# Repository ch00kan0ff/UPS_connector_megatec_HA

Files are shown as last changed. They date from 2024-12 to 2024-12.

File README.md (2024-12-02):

# Монитор ИБП с протоколом Megatec для HomeAssistant
Устройство на базе контроллера ESP8266 для получения данных по RS232 от источника бесперебойного питания (ИБП) и передачи их в HomeAssistant.

## Схема
Схема сборки на рисунке ниже. Исходник схемы, если надо /files/UPS_Control.fzz

**Важно!** Если не заработало после сборки, то можно попробовать менять местами RX-TX. Их тут две пары: от контроллера к преобразователю и от преобразователя к плате ИБП. То, как указано на схеме работает в моем случае.
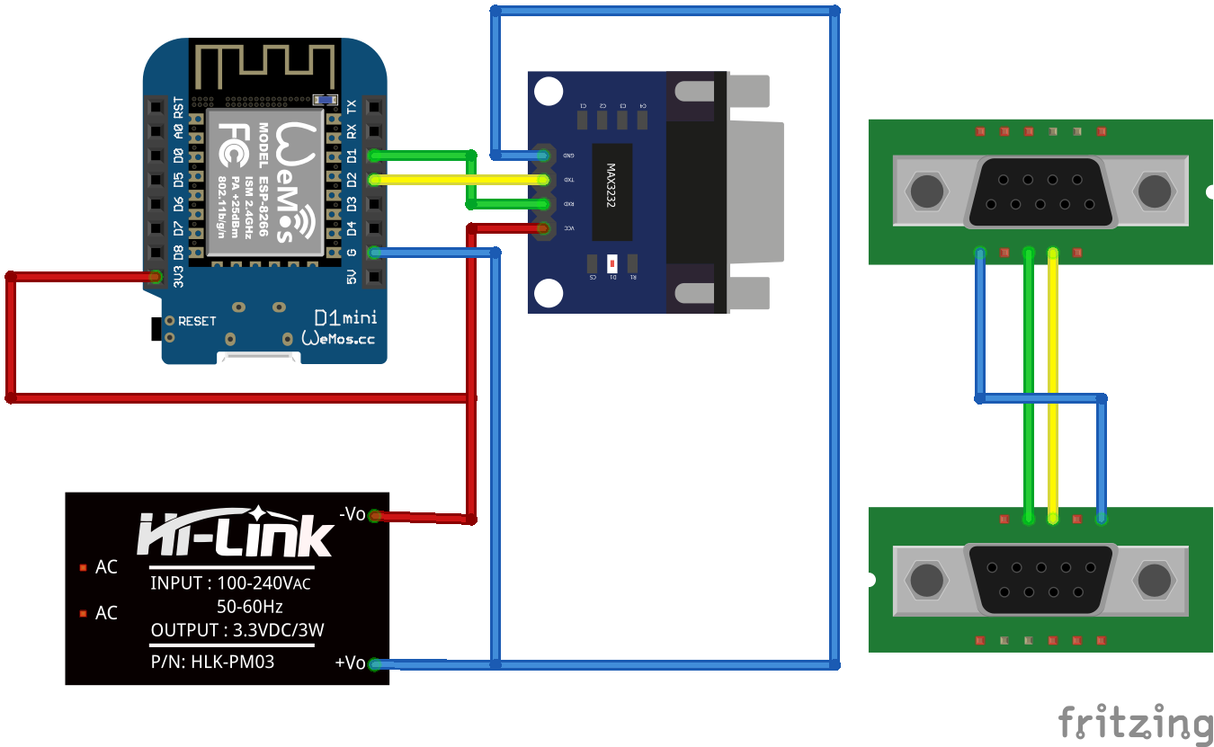
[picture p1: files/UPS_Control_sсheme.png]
Схема сборки устройства


Вместо Wenmos вполне можно использовать другие контроллеры, но тестировалось только на нём. В качестве преобразователя нужен MAX3232, так как он работает от 3.3V. MAX232 судя по всему только от 5 вольт.

## Прошивка
Разрабатывал и прошивал в ArduinoIDE. Файл прошивки /src/UPS_Connector.ino. Для сборки прошики нужны некоторые библиотеки, ссылки на них указаны в комментариях в самом коде прошивки. Все устанавливаются через менеджер библиотек ArduinoIDE. Для работы ESPSoftwareSerial нужна последняя версия платы, поэтому перед сборкой лучше обновить платы.

Настройки прошивки можно не трогать, если паять по схеме. Либо поменять пины для ESPSoftwareSerial, если используете другие пины. 

Перед прошивкой желательно затереть Flash память, так как используется сохранение настроек в память и при наличии там мусора могут быть проблемы. На новых модулях этого можно не делать, должно работать и так.

Для wemos выложен также готовый бинарник, можно прошить его, если ничего не планируете менять в самой прошивке. Файл в /bin/UPS_connector.ino.d1_mini.bin

## Возможности
### Сбор данных с ИБП
Реализован опрос ИБП по протоколу Megatec, сделано получение следующих данных:
- InputVoltage. Входное напряжение
- FailVoltage. Напряжение ошибки
- OutputVoltage. Выходное напряжение
- Output load. Загрузка ИБП по току в процентах от максимальной загрузки.
- InputFrequency. Частота тока. По протоколу написано, что это для входной линии, судя по тестам - для выходной. Однако, оставлено так, потому что не смог понять, это особенность моего тестового ИБП или всё-таки стандарт.
- BatteryVoltage. Напряжение батареи. Для On-line ИБП выдает напряжение на одной банке. Для корректного отображения в HA на портале есть множители. Смотри ниже в описании портала.
- Tempetature. Температура ИБП.
- UtilityFail. Флаг ошибки, когда возникают проблемы с вводной сетью.
- LowBattery. Флаг ошибки при низком заряде батареи.
- Bypass. Сигнал включенного байпаса.
- GeneralFail. Что-то типа общей ошибки в работе ИБП.
- OnLine. Тип ИБП. Если включено, значит On-line.
- TestInProgress. Флаг запущенного теста батарей.
- ShutDownActive. Флаг того, что запущен процесс выключения ИБП.
- Beeper. Состояние звукового сигнала.

И отдельно сделан параметр потери связи с ИБП ConnectionFail. Возводится если контроллер не может долго получить данные от ИБП. В таком случае он будет пытаться восстановить связь раз в 5 минут автоматически.

### Передача данных в HA
Подключение через службу MQTT с AutoDyscovery. Чтобы устранить возможные конфликты - сделана автоматическая генерация GUID при первом старта устройства или при затирании flash.
Само устройство после добавления выглядит так:

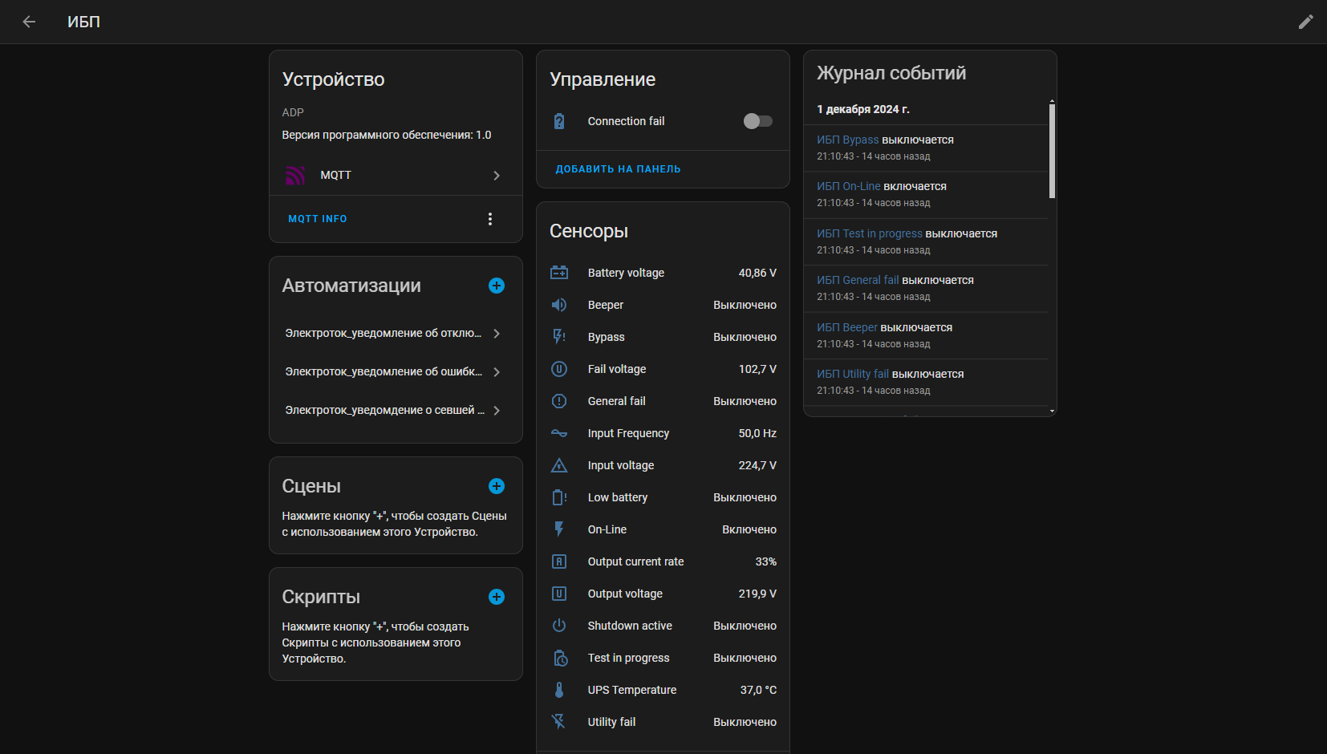
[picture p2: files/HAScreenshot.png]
HAScreenshot


Сделана дополнительная карточка для большей наглядности. При создании карточки использовались стандартная карточка picture-elements, [custom:button-card](https://github.com/custom-cards/button-card) и [cardmod](https://github.com/thomasloven/lovelace-card-mod).
Вид карточки показан на скриншоте снизу. Исходник картинки подложки (GIMP) лежит тут: files/HAUPSCardBackground.xcf. Сама картинка подложка тут: HA_Card/HAUPSCardBackground.xcf. YAML карточки тут: HA_Card/HA_card.yaml. В карточке надо будет указать корректные наименования объектов, так как они будут сохранены в HA.

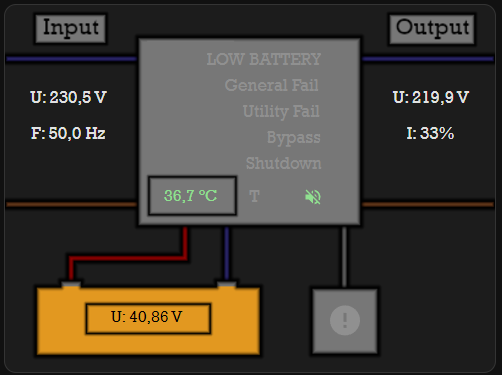
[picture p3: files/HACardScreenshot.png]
HACardScreenshot


ConnectionFail в HA сделан выключателем. И его можно выключить, тогда контроллер попытается восстановить связь с ИБП. При включении этого выключателя, связь с ИБП не будет прерываться и состояние выключателя вернется в выключенное состояние.

При потере питания, отвала сети и т.д. устройство в HA помечается недоступным спустя минуту (примерно).

### Портал на устройстве и настройки
Реализован портал, для настройки подключения и получения данных с устройства без HA. После первого включения устройства, создается точка доступа UPSControl с паролем 1234567890 (можно поменять в настройках). После подключения к ней надо перейти по адресу 192.168.1.1. Откроется окно портала. Там нужно ввести реквизиты доступа к Wi-Fi и подключения к MQTT серверу, к которому подключен HA. Топик для дискавери по умолчанию установлен стандартный homeassistant, если необходимо, то можно его поменять. После нажатия Save and Connect контроллер пытается подключиться к сети и MQTT серверу. Если коннект успешен, то контроллер начинает отправлять данные в HA. На портал в таком случае можно зайти, перейдя в браузере по IP, который выделил для контроллера роутер.

Сделано автоматическое восстановление связи с Wi-Fi и MQTT. Если коннект пропал, то контроллер поднимает точку доступа UPSControl, как при первом старте. И пытается раз 3 минуты подключиться заново.

Помимо настроек сети на портале доступно:
- Просмотр всех параметров, полученных от ИБП. Обновляются онлайн.
- Выключение ConnectionFail по аналогии с таким выключателем в HA (смотри выше).
- Настройка батарей. Можно указать сколько ячеек в одной батарее и сколько последовательно соединено батарей в сборке. На основе этой информации контроллер считает вольтаж всей баратеи и именно эту цифру передает в HA и на портал.
- OTA обновления прошивки по воздуху. Доступно через отдельную страницу 192.168.1.1/ota_update, либо надо указать IP адрес от роутера вместо "192.168.1.1".

Скриншоты портала ниже:

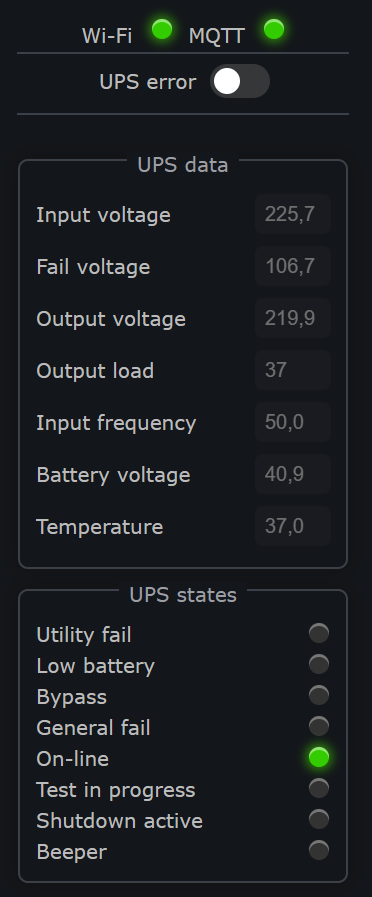
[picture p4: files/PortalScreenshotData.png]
PortalScreenshotData


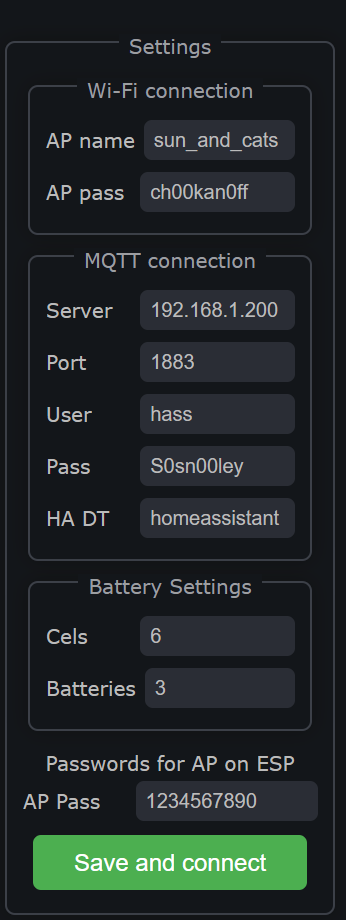
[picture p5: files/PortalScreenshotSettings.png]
PortalScreenshotSettings


## Поддерживаемые ИБП
По идее должны поддерживаться любые ИБП с протоколом Megatec и выходом RS232. Однако тестировалось только на [Штиль SW1000L](https://www.shtyl.ru/catalog/ibp/odnofaznye/nastennye/sw1000l-1000-va-900-vt/) с картой расширения [IC-RS232/Dry contacts](https://www.shtyl.ru/catalog/ibp/aksessuary/karty-monitoringa/ic-rs-232-dry-contacts/)

## TODO
В будущем планируется сделать отправку дополнительных команд на ИБП:
- Включение/отключение звука
- Запуск/остановка тестов

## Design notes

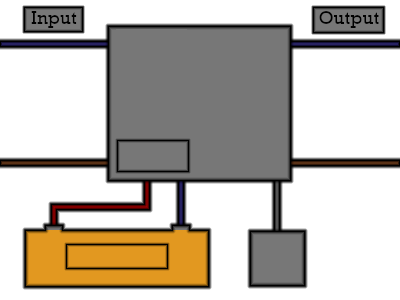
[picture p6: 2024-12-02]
HA_card/HAUPSCardBackground.png

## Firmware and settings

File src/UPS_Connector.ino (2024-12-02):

/*-----Подключение необходимых библиотек-----*/
#include <ESP8266WiFi.h>                //для работы с сетью
#include <GyverPortal.h>                //для работы страницы настроек, доступной из локальной сети или при подключении к самому устройству. https://github.com/GyverLibs/GyverPortal/tree/main
#include <EEPROM.h>                     //для работы с памятью
#include <ArduinoHA.h>                  //Библиотека для отправки данных в HA. https://github.com/dawidchyrzynski/arduino-home-assistant
#include <SoftwareSerial.h>             //Библиотека для обмена через софт сериал. Через аппаратный оно не особо хотело работать. https://github.com/plerup/espsoftwareserial
extern "C" {
#include "user_interface.h"             //для переименования устройства в списке роутера
}

/*-----Объявление необходимых переменных-----*/
GyverPortal portal;                     //переменная портала
WiFiClient espClient;                   //переменная wi-fi клиента, через которого в дальнейшем подключаемся к сети

//Переменные для обмена с HA
HADevice device;
HAMqtt mqtt(espClient, device, 20);     //20 - количество сенсоров. Взято с запасом, на всякий случай. Думаю, что можно уменьшить до реального количества сенсоров
HASensorNumber sIPV("InputVoltage", HASensorNumber::PrecisionP1);
HASensorNumber sFV("FailVoltage", HASensorNumber::PrecisionP1);
HASensorNumber sOPV("OutputVoltage", HASensorNumber::PrecisionP1);
HASensorNumber sOPC("Output load");
HASensorNumber sIPF("InputFrequency", HASensorNumber::PrecisionP1);
HASensorNumber sBATV("BatteryVoltage", HASensorNumber::PrecisionP2);
HASensorNumber sTEMP("Tempetature", HASensorNumber::PrecisionP1);
HABinarySensor sUF("UtilityFail");//b7
HABinarySensor sLB("LowBattery");//b6
HABinarySensor sBA("Bypass");//b5
HABinarySensor sGF("GeneralFail");//b4
HABinarySensor sOL("OnLine");//b3
HABinarySensor sTP("TestInProgress");//b2
HABinarySensor sSD("ShutDownActive");//b1
HABinarySensor sBP("Beeper");//b0
HASwitch sCF("ConnectionFail");


static DNSServer _SP_dnsServer;         //переменная для DNS сервера

#define SP_AP_IP 192,168,1,1            //IP адрес портала для работы в режиме поднятой точки доступа на ESP
IPAddress apIP(SP_AP_IP);               //переменная для адреса, определенного в строке выше
IPAddress subnet(255, 255, 255, 0);     //подсеть
IPAddress nullAddr(0,0,0,0);            //пустой адрес, для сброса настроек

EspSoftwareSerial::UART mySerial;       //Объявляем порт

String WIFI_AP_NAME;                    //наименование точки доступа для подключения к wi-fi
String WIFI_PASSWORD;                   //пароль для подключения к точке доступа
String MQTT_ADR;                        //адрес mqtt сервера
String MQTT_PORT;                       //порт mqtt сервера
String MQTT_USER;                       //имя пользователя для подключения к mqtt
String MQTT_PAS;                        //пароль для  подключения к mqtt
String WIFI_SOFTAP_PAS;                 //пароль для точки доступа, которая поднимается на ESP. Если не задан, то по умолчанию 1234567890
int status = WL_IDLE_STATUS;            //статус соединения Wi-Fi
unsigned long lastReconnectAttempt = 0; //время последней попытки подключения к mqtt


bool WiFiStatus;                        //Статус Wi-fi подключения к роутеру: 1-ОК, 0 не ОК
bool mode = 0;                          //Переменная режима работы сети: 1 - точка доступа на ESP, 0 - работа в локальной сети

bool isConnectionCrash = 0;             //флаг того, что соединение с Wi-Fi
unsigned long lastCrashReconnect = 0;   //переменная для хранения времени последней попытки подключения при аварии
unsigned long UPSConnectCrash = 0;      //переменная для хранения времени отвала связи с ИБП для попытки восстановления

byte firstStart;                        //Переменная для первого запуска. 137 - НЕ первый старт, всё остальное - первый старт

// Переменные для получения данных от ИБП. Стандарт написан тут: https://networkupstools.org/protocols/megatec.html
float ipv;        //Входное напряжение
float fv;         //Напряжение ошибки
float opv;        //Выходное напряжение
int opc;          //Ток потребителей
float ipf;        //Входная частота тока
float batv;       //Напряжение батареи
float temp;       //Температура
int b7;           //Ошибка сети
int b6;           //Батарея разряжена
int b5;           //Байпас включен
int b4;           //Общая ошибка ИБП
int b3;           //ИБП в режиме ожидания, 0 в работе
int b2;           //Идет тест
int b1;           //Включено завершение работы
int b0;           //Сигнал включен

//Дополнительные переменные
int cDelay = 100;               //Период отправки сообщений. То что тут указано позже в коде меняется на 10000. Учитывая, что команды отправляются по очереди F и Q1, то реальный интервал получения данных будет раз в 20 секунд.
int cTimer = 0;                 //Переменная таймер для отправки сообщений
int rDelay = 9000;              //Период ожидания ответа от ИБП после отправки команды
int rTimer = 0;                 //Переменная таймер для ожидания ответа
int notGetDataCounter = 0;      //Счётчик неполученных ответов
bool isDataGetted = true;       //Флаг успешного приема данных
bool isUPSUnavailable = false;  //Флаг недоступности ИБП
String devGuid;                 //идентификатор устройства
String HADiscoveryTopic;        //Топик для автоопределения в HA 
bool isSendF = false;           //Маркер отправки команды F
int cellCount = 0;              //Количество ячеек в батарее, для 12 вольтовой батареи это 6
int batCount = 0;               //Количество батарей, подключенных последовательно!

/*-----Функция разбора строки, полученной от ИБП-----*/
void parseUPSResponse(String str){
  str = str.substring(1);  //первым символом там скобка, отрезаем его
  ipv = (str.substring(0,5)).toFloat();
  fv = (str.substring(6,11)).toFloat();
  opv = (str.substring(12,17)).toFloat();
  opc = (str.substring(18,21)).toInt();
  ipf = (str.substring(22,26)).toFloat();
  batv = (str.substring(27,31)).toFloat();
  batv = batv * cellCount * batCount;
  temp = (str.substring(32,36)).toFloat();
  b7 = (str.substring(37,38)).toInt();
  b6 = (str.substring(38,39)).toInt();
  b5 = (str.substring(39,40)).toInt();
  b4 = (str.substring(40,41)).toInt();
  b3 = (str.substring(41,42)).toInt();
  b2 = (str.substring(42,43)).toInt();
  b1 = (str.substring(43,44)).toInt();
  b0 = (str.substring(44,45)).toInt();
}

/*------Конструктор страницы портала-----*/
void build(){
  GP.BUILD_BEGIN();
  GP.THEME(GP_DARK);
  GP.PAGE_TITLE("UPS Control");
  GP.UPDATE("wfst,mqst,sw,pIPV,pFV,pOPV,pOPC,pIFP,pBATV,pTEMP,pUF,pLB,pBA,pGF,pOL,pTP,pSD,pBP",cDelay);

  GP.LABEL("Wi-Fi ");
  GP.LED_GREEN("wfst",WiFiStatus);            
  GP.LABEL(" MQTT ");
  GP.LED_GREEN("mqst",mqtt.isConnected());
  GP.BREAK();
  GP.HR();

  GP.LABEL("UPS error ");
  GP.SWITCH("sw", isUPSUnavailable);
  GP.BREAK();
  GP.HR();
  GP.BREAK();

  GP.BLOCK_BEGIN(GP_THIN,"100%","UPS data");
  GP.BOX_BEGIN();
  GP.LABEL("Input voltage");
  GP.NUMBER_F("pIPV", "", ipv, 1, "25%", true);
  GP.BOX_END();
  GP.BOX_BEGIN();
  GP.LABEL("Fail voltage");
  GP.NUMBER_F("pFV", "", fv, 1, "25%", true);
  GP.BOX_END();
  GP.BOX_BEGIN();
  GP.LABEL("Output voltage");
  GP.NUMBER_F("pOPV", "", opv, 1, "25%", true);
  GP.BOX_END();
  GP.BOX_BEGIN();
  GP.LABEL("Output load");
  GP.NUMBER("pOPC", "", opc, "25%", true);
  GP.BOX_END();
  GP.BOX_BEGIN();
  GP.LABEL("Input frequency");
  GP.NUMBER_F("pIFP", "", ipf, 1, "25%", true);
  GP.BOX_END();
  GP.BOX_BEGIN();
  GP.LABEL("Battery voltage");
  GP.NUMBER_F("pBATV", "", batv, 2, "25%", true);
  GP.BOX_END();
  GP.BOX_BEGIN();
  GP.LABEL("Temperature");
  GP.NUMBER_F("pTEMP", "", temp, 1, "25%", true);
  GP.BOX_END();
  GP.BLOCK_END();

  GP.BLOCK_BEGIN(GP_THIN,"100%","UPS states");
  GP.BOX_BEGIN();
  GP.LABEL("Utility fail");
  GP.LED_RED("pUF",b7);
  GP.BOX_END();
  GP.BOX_BEGIN();
  GP.LABEL("Low battery");
  GP.LED_RED("pLB",b6);
  GP.BOX_END();
  GP.BOX_BEGIN();
  GP.LABEL("Bypass");
  GP.LED_RED("pBA",b5);
  GP.BOX_END();
  GP.BOX_BEGIN();
  GP.LABEL("General fail");
  GP.LED_RED("pGF",b4);
  GP.BOX_END();
  GP.BOX_BEGIN();
  GP.LABEL("On-line");
  GP.LED_GREEN("pOL",!b3);
  GP.BOX_END();
  GP.BOX_BEGIN();
  GP.LABEL("Test in progress");
  GP.LED_RED("pTP",b2);
  GP.BOX_END();
  GP.BOX_BEGIN();
  GP.LABEL("Shutdown active");
  GP.LED_GREEN("pSD",b1);
  GP.BOX_END();
  GP.BOX_BEGIN();
  GP.LABEL("Beeper");
  GP.LED_GREEN("pBP",b0);
  GP.BOX_END();
  GP.BLOCK_END();

  GP.BREAK();
  GP.HR();
  GP.BREAK();
  
  GP.FORM_BEGIN("/update");
  GP.BLOCK_BEGIN(GP_THIN,"100%","Settings");
  GP.BLOCK_BEGIN(GP_THIN,"95%","Wi-Fi connection");
  GP.BOX_BEGIN();
  GP.LABEL("AP name");
  GP.TEXT("wfname", "Name", WIFI_AP_NAME,"60%");
  GP.BOX_END();
  GP.BOX_BEGIN();
  GP.LABEL("AP pass");
  GP.TEXT("wfpas", "Pass", WIFI_PASSWORD,"60%");
  GP.BOX_END();
  GP.BLOCK_END();
  
  GP.BLOCK_BEGIN(GP_THIN,"95%","MQTT connection");
  GP.BOX_BEGIN();
  GP.LABEL("Server");
  GP.TEXT("ser", "Server", MQTT_ADR,"60%");
  GP.BOX_END();
  GP.BOX_BEGIN();
  GP.LABEL("Port");
  GP.TEXT("port", "Port", MQTT_PORT,"60%");
  GP.BOX_END();
  GP.BOX_BEGIN();
  GP.LABEL("User");
  GP.TEXT("user", "User", MQTT_USER,"60%");
  GP.BOX_END();
  GP.BOX_BEGIN();
  GP.LABEL("Pass");
  GP.TEXT("pas", "Password", MQTT_PAS,"60%");
  GP.BOX_END();
  GP.BOX_BEGIN();
  GP.LABEL("HA DT","hadtl");
  GP.HINT("hadtl", "HomeAssistant discovery topic");
  GP.TEXT("hadt", "homeassistant", HADiscoveryTopic,"60%");
  GP.BOX_END();
  GP.BLOCK_END();

  GP.BLOCK_BEGIN(GP_THIN,"95%","Battery Settings");
  GP.BOX_BEGIN();
  GP.LABEL("Cels","ccl");
  GP.HINT("ccl", "Cells count in one battery, usually 6 fo 12V battery");
  GP.NUMBER("cel", "cells", cellCount,"60%");
  GP.BOX_END();
  GP.BOX_BEGIN();
  GP.LABEL("Batteries","batcl");
  GP.HINT("batcl", "Batteries count, connected in series");
  GP.NUMBER("batc", "Batteries", batCount,"60%");
  GP.BOX_END();
  GP.BLOCK_END();

  GP.LABEL("Passwords for AP on ESP");
  GP.BREAK();
  GP.BOX_BEGIN();
  GP.LABEL("AP Pass");
  GP.TEXT("sappas", "Password", WIFI_SOFTAP_PAS,"60%");
  GP.BOX_END();
  GP.SUBMIT("Save and connect");
  GP.FORM_END();
  GP.BLOCK_END();

  GP.BLOCK_BEGIN(GP_THIN,"300px");
  GP.LABEL("You chose to open this page from local network (LN) or from access point (AP), runing on controller","lbLNAP",GP_DEFAULT,0,0,1); GP.BREAK();
  GP.LABEL("LN");
  GP.SWITCH("mode", mode);
  GP.LABEL("AP");
  GP.BREAK();
  GP.BLOCK_END();
  
  GP.BUILD_END();
}

/*-----Функция записи строки в память. Записывает строку побайтно в память начиная с addrOffset, и возвращает адрес, с которого можно начинать писать следующую строку-----*/
int writeStringToEEPROM(int addrOffset, const String &strToWrite){
  byte len = strToWrite.length();
  EEPROM.begin(512);
  EEPROM.write(addrOffset, len);
  EEPROM.end();
  for (int i = 0; i < len; i++){
    EEPROM.begin(512);
    EEPROM.write(addrOffset + 1 + i, strToWrite[i]);
    EEPROM.end();
  }
  return addrOffset + 1 + len;
}
/*-----Функция чтения строки из памяти. Побайтно считывает строку начиная с addrOffset, и возвращает адрес, с которого можно начинать читать следующую строку-----*/
int readStringFromEEPROM(int addrOffset, String *strToRead){
  EEPROM.begin(512);
  int newStrLen = EEPROM.read(addrOffset);
  EEPROM.end();
  char data[newStrLen + 1];
  for (int i = 0; i < newStrLen; i++){
    EEPROM.begin(512);
    data[i] = EEPROM.read(addrOffset + 1 + i);
    EEPROM.end();
  }
  data[newStrLen] = '\0';
  *strToRead = String(data);
  return addrOffset + 1 + newStrLen;
}

/*-----Функция обработчик событий на портале*/
void action(){
  if (portal.click()){
    if (portal.click("sw")){ //Обработка клика по выключателю
      if (isUPSUnavailable){  
        notGetDataCounter = 0; 
        isUPSUnavailable = false;
      }
    }
    if (portal.click("mode")){ //Обработка клика по переключателю режимов работы сети
      mode = !mode;
      EEPROM.begin(512);
      EEPROM.write(2, mode);
      EEPROM.end();
      if(mode){
        connect_AP();
      }
      else{
        connect_STA();
      }
    }
  }

  // обработка клика по форме
  if (portal.form()) {
    if (portal.form("/update")) {
      //забираем значения и обновляем переменные
      WIFI_AP_NAME = portal.getString("wfname");
      WIFI_PASSWORD = portal.getString("wfpas");
      MQTT_ADR = portal.getString("ser");
      MQTT_PORT = portal.getString("port");
      MQTT_USER = portal.getString("user");
      MQTT_PAS = portal.getString("pas");
      WIFI_SOFTAP_PAS = portal.getString("sappas");
      HADiscoveryTopic = portal.getString("hadt");
      cellCount = portal.getInt("cel");
      batCount = portal.getInt("batc");
      //запишем полученное в память
      int eepromOffset = 4;
      int newStr1AddrOffset = writeStringToEEPROM(eepromOffset, WIFI_AP_NAME);
      int newStr2AddrOffset = writeStringToEEPROM(newStr1AddrOffset, WIFI_PASSWORD);
      int newStr3AddrOffset = writeStringToEEPROM(newStr2AddrOffset, MQTT_ADR);
      int newStr4AddrOffset = writeStringToEEPROM(newStr3AddrOffset, MQTT_PORT);
      int newStr5AddrOffset = writeStringToEEPROM(newStr4AddrOffset, MQTT_USER);
      int newStr6AddrOffset = writeStringToEEPROM(newStr5AddrOffset, MQTT_PAS);
      int newStr7AddrOffset = writeStringToEEPROM(newStr6AddrOffset, WIFI_SOFTAP_PAS);
      int newStr8AddrOffset = writeStringToEEPROM(newStr7AddrOffset, devGuid);
      int newStr9AddrOffset = writeStringToEEPROM(newStr8AddrOffset, HADiscoveryTopic);
      EEPROM.begin(512);
      EEPROM.write(newStr9AddrOffset, cellCount);
      EEPROM.end();
      EEPROM.begin(512);
      EEPROM.write(newStr9AddrOffset+5, batCount);
      EEPROM.end(); 
      
      mqtt.disconnect();//отключаем mqtt, он в основном цикле включится уже с новыми параметрами
      mqtt.setDiscoveryPrefix(HADiscoveryTopic.c_str()); //обновляем топик для дискавери
      
      //Изменим режим работы сети на работу в локальной сети и сохраним это в памяти
      mode = 0;
      EEPROM.begin(512);
      EEPROM.write(2, mode);
      EEPROM.end();
      //Подключимся к локальной сети
      connect_STA();
    }
  }
  if (portal.update()){//обновляем значения в полях на портале
    portal.updateBool("wfst",WiFiStatus);
    portal.updateBool("mqst",mqtt.isConnected());
    portal.updateBool("sw", isUPSUnavailable);
    portal.updateFloat("pIPV", ipv, 1);
    portal.updateFloat("pFV", fv, 1);
    portal.updateFloat("pOPV", opv, 1);
    portal.updateInt("pOPC", opc);
    portal.updateFloat("pIFP", ipf, 1);
    portal.updateFloat("pBATV", batv, 1);
    portal.updateFloat("pTEMP", temp, 1);
    portal.updateBool("pUF",b7);
    portal.updateBool("pLB",b6);
    portal.updateBool("pBA",b5);
    portal.updateBool("pGF",b4);
    portal.updateBool("pOL",!b3);
    portal.updateBool("pTP",b2);
    portal.updateBool("pSD",b1);
    portal.updateBool("pBP",b0);
  }
}

/*-----Функция подключения к локальной сети-----*/
void connect_STA(){
  WiFi.softAPdisconnect (true);                   //отключаем точку доступа на ESP
  WiFi.softAPConfig(nullAddr, nullAddr, subnet);  //сбиваем её настройки
  _SP_dnsServer.stop();                           //останавливаем DNS сервер
  WiFi.mode(WIFI_STA);                            //переключаем wi-fi модуль в режим подключения к роутеру
  wifi_station_set_hostname("UPS Control");       //устанавливаем наименование устройства (будет видно в списке роутера)
  InitWiFi();                                     //подключаемся к роутеру
  _SP_dnsServer.start(53, "*", apIP);             //стартуем заново DNS сервер
  portal.stop();                                  //Перезапускаем портал на всякий случай
  portal.start();
}

/*-----Функция создания точки доступа на ESP-----*/
void connect_AP(){
  if (WiFi.softAPIP() != apIP){                   //проверяем, что точка доступа уже не поднята
    WiFi.mode(WIFI_AP);                           //переключаем wi-fi модуль в режим точки доступа
    WiFi.softAPConfig(apIP, apIP, subnet);        //настраиваем точку доступа
    //настроим наименование точки доступа в зависимости от наименования клиента
    String SoftAPName = "UPS_Control";
    //настроим пароль точки доступа в зависимости от настроек
    String SoftAPPas;
    if (WIFI_SOFTAP_PAS == ""){                   //если пароль не был задан через портал, то оставляем стандартный, если был задан, то используем его
      SoftAPPas = "1234567890";
    }
    else{
      SoftAPPas = WIFI_SOFTAP_PAS;
    }
    WiFi.softAP(SoftAPName.c_str(), SoftAPPas.c_str()); //включаем точку доступа
    _SP_dnsServer.start(53, "*", apIP);                 //запускаем DNS сервер
    portal.stop();                                      //Перезапускаем портал на всякий случай
    portal.start();
  }
}

/*-----Функция подключения к Wi-fi-----*/
void InitWiFi(){
  int attemptsCount = 0;                    //количество попыток подключения
  WiFi.begin(WIFI_AP_NAME, WIFI_PASSWORD);  //пробуем подключиться
  while (WiFi.status() != WL_CONNECTED){    //ждём подключения
    attemptsCount++;
    if (attemptsCount > 60){                //если попыток подключения слишком много, то прекращаем их и устанавливаем флаг плохого подключения
      WiFiStatus = 0;
      break;
    }
    delay(500);
  }
  if (WiFi.status() == WL_CONNECTED){
    WiFiStatus = 1;                         //если подключились, то ставим флаг хорошего подключения
  }
}
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
void loop() {
  if (WiFi.status() != WL_CONNECTED && !mode){
    connect_STA(); //если отвалился коннект к роутеру и в режиме работы в локальной сети, то пробуем подключиться заново
  }
  if (!portal.tick()){ //проверяем состояние работы портала
      portal.start();
    }  
    
  if (!mode && WiFiStatus){  //если включен режим работы в локальной сети и вайфай подключен, то подключаемся к брокеру
    if(!mqtt.isConnected()){
      if(MQTT_ADR != ""){
        if (millis() - lastReconnectAttempt > 5000 || millis() < 5000){
          mqtt.begin(MQTT_ADR.c_str(), MQTT_PORT.toInt(), MQTT_USER.c_str(), MQTT_PAS.c_str()); //включаем MQTT
        }
      }
    }
    mqtt.loop();//Если поключено, то вызовем тик mqtt
  }
  
  if(!WiFiStatus){  //если соединение с wi-fi отвалилось
    if(isConnectionCrash && millis() - lastCrashReconnect > 180000 && WiFi.softAPgetStationNum() == 0){ //проверяем, что с момента обрыва прошло три минуты и никто не подключен к точке доступа. Это нужно чтобы пытаться восстанавливать связь при обрывах
      if (mode){ //меняем режим на подключение по локальной сети
        mode = false;
        EEPROM.begin(512);
        EEPROM.write(2, mode);
        EEPROM.end();
        isConnectionCrash = false;  //и снимаем флаг того, что соединение отвалилось
      }
    }
    else{
      if (!mode){  //для этого меняем режим, если он не был поменян до этого
        mode = true;
        EEPROM.begin(512);
        EEPROM.write(2, mode);
        EEPROM.end();
        lastCrashReconnect = millis();  //запоминаем время возникновения обрыва
        isConnectionCrash = true;       //и взводим флаг обрыва
      }  
      connect_AP();       //и создаем точку доступа на ESP
    }
  }

  //Раз в период отправки команды и если порт чист (всё считано ранее) отправляем команду на получение данных. Команда не отправляется, если ИБП недоступен
  if (millis() - cTimer > cDelay && !isUPSUnavailable){
    if (cDelay != 10000){ //это для первого прохода. Если не делать, то первая команда отправляется через минуту после старта контроллера, что не очень приятно
      cDelay = 10000;
    }
    if (isDataGetted){
      isDataGetted = false;
      notGetDataCounter = 0;
    }
    else{
      notGetDataCounter++;
      if (notGetDataCounter > 10){
        isUPSUnavailable = true;
        UPSConnectCrash = millis(); //запомним, когда отвалилась связь
        sCF.setState(true); //отправим в HA печальную весть
      }
      else{
        isDataGetted = false;
      }
    }
    if (!isUPSUnavailable){
      mySerial.readString(); //очищаем ввод

      

      if(isSendF){
        mySerial.write("Q1\r");  //Отправляем команду на ИБП для получения данных
        isSendF = false;
      }
      else{
        mySerial.write("F\r");  //Или дежурную команду (без нее не работает, но её результаты в принципе не нужны, так как всё есть в Q1)
        isSendF = true;
      }
      cTimer = millis();
      rTimer = millis();
    }
  }

  //После отправки команды в ИБП пробуем получить ответ и разобрать его. Если ИБП недоступен, то считывание данных не производится
  if (millis() - rTimer < rDelay && !isUPSUnavailable){
    if(mySerial.available() > 0 && !isDataGetted && !isUPSUnavailable){ //Если данные получены от ИБП, то разбираем их на переменные
      String str = mySerial.readString();
      if(!isSendF){
        parseUPSResponse(str); //если отправляли F, то не разбираем их, а просто считываем буфер для очистки
      }
      isDataGetted = true;
      
      /*Отправим полученные данные в HA*/
      if (mqtt.isConnected()){
        sIPV.setValue(ipv);
        sFV.setValue(fv);
        sOPV.setValue(opv);
        sOPC.setValue(opc);
        sIPF.setValue(ipf);
        sBATV.setValue(batv);
        sTEMP.setValue(temp);
        sUF.setState(b7);
        sLB.setState(b6);
        sBA.setState(b5);
        sGF.setState(b4);
        sOL.setState(!b3);
        sTP.setState(b2);
        sSD.setState(b1);
        sBP.setState(b0);
      }
    }
  }
  if(isUPSUnavailable && millis() - UPSConnectCrash > 300000){ //если связи с ИБП нет, то пробуем раз в 5 минут её восстановить
    notGetDataCounter = 0;
    isUPSUnavailable = false;
  }

}

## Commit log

2024-11-27 Update UPS_Connector.ino
    Fix connection problems and some improvments
    [UPS_Connector.ino]
2024-12-02 ADD scheme and some additional files
    [UPS_Control.fzz]
2025-11-02 Update HA_card.yaml fix error in sensor T
